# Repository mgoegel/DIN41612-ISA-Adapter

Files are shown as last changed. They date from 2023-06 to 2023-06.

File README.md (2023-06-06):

# DIN41612 to ISA Adapter

Here, I created a KiCad 6 Project.

The goal was, to create a PCB for debugging/testing of robotron EC1834 addon Boards on Standard XT PCs.

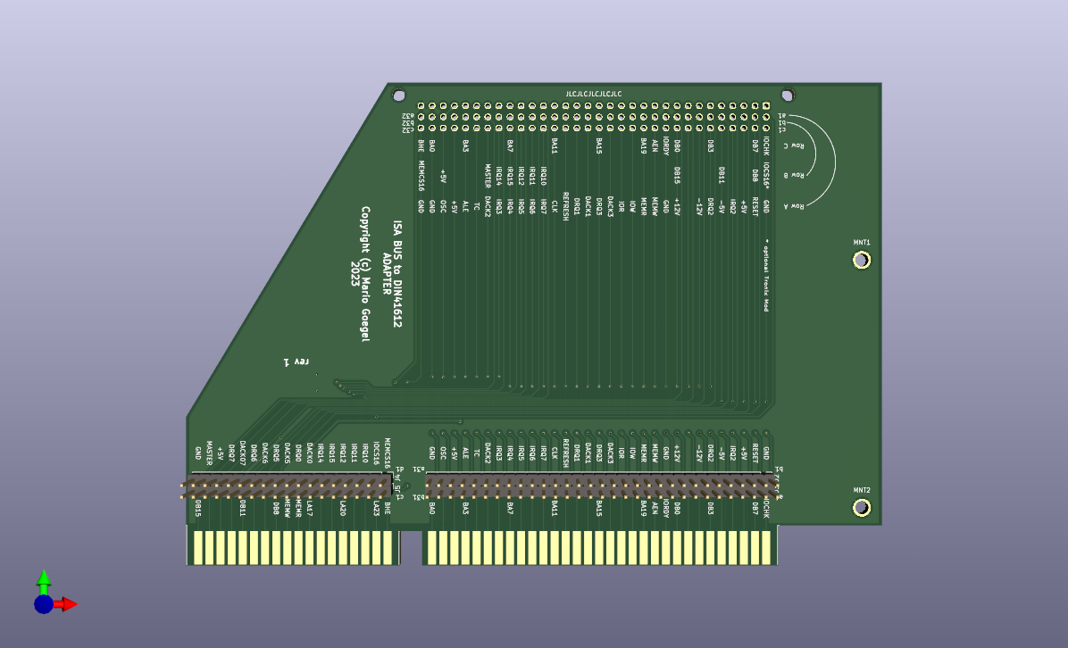
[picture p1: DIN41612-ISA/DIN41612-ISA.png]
DIN41612-ISA


[Schematics](DIN41612-ISA/DIN41612-ISA.pdf)

Below is the Bill of Materials for the board:

```
Ref(s)      Value                               Mouser P/N
-------------------------------------------------------------------------------
J1          DIN 41612 Type R a+b+c 3x32 PINs    649-8693968837V1LF  
            (96 PINs) Receptacles
J2, J3      13x1 header                         538-22-28-4200 (See Note 1)
J4, J5      31x1 header                         538-22-28-4200 (See Note 1)
BRACKET     Keystone 9202 ISA bracket           534-9202
SCREWS      4-40 x 1/4" machine screw           534-9301
```

But the 
Note 1: Order a 20 (or greater) breakaway header, break into the required lengths.

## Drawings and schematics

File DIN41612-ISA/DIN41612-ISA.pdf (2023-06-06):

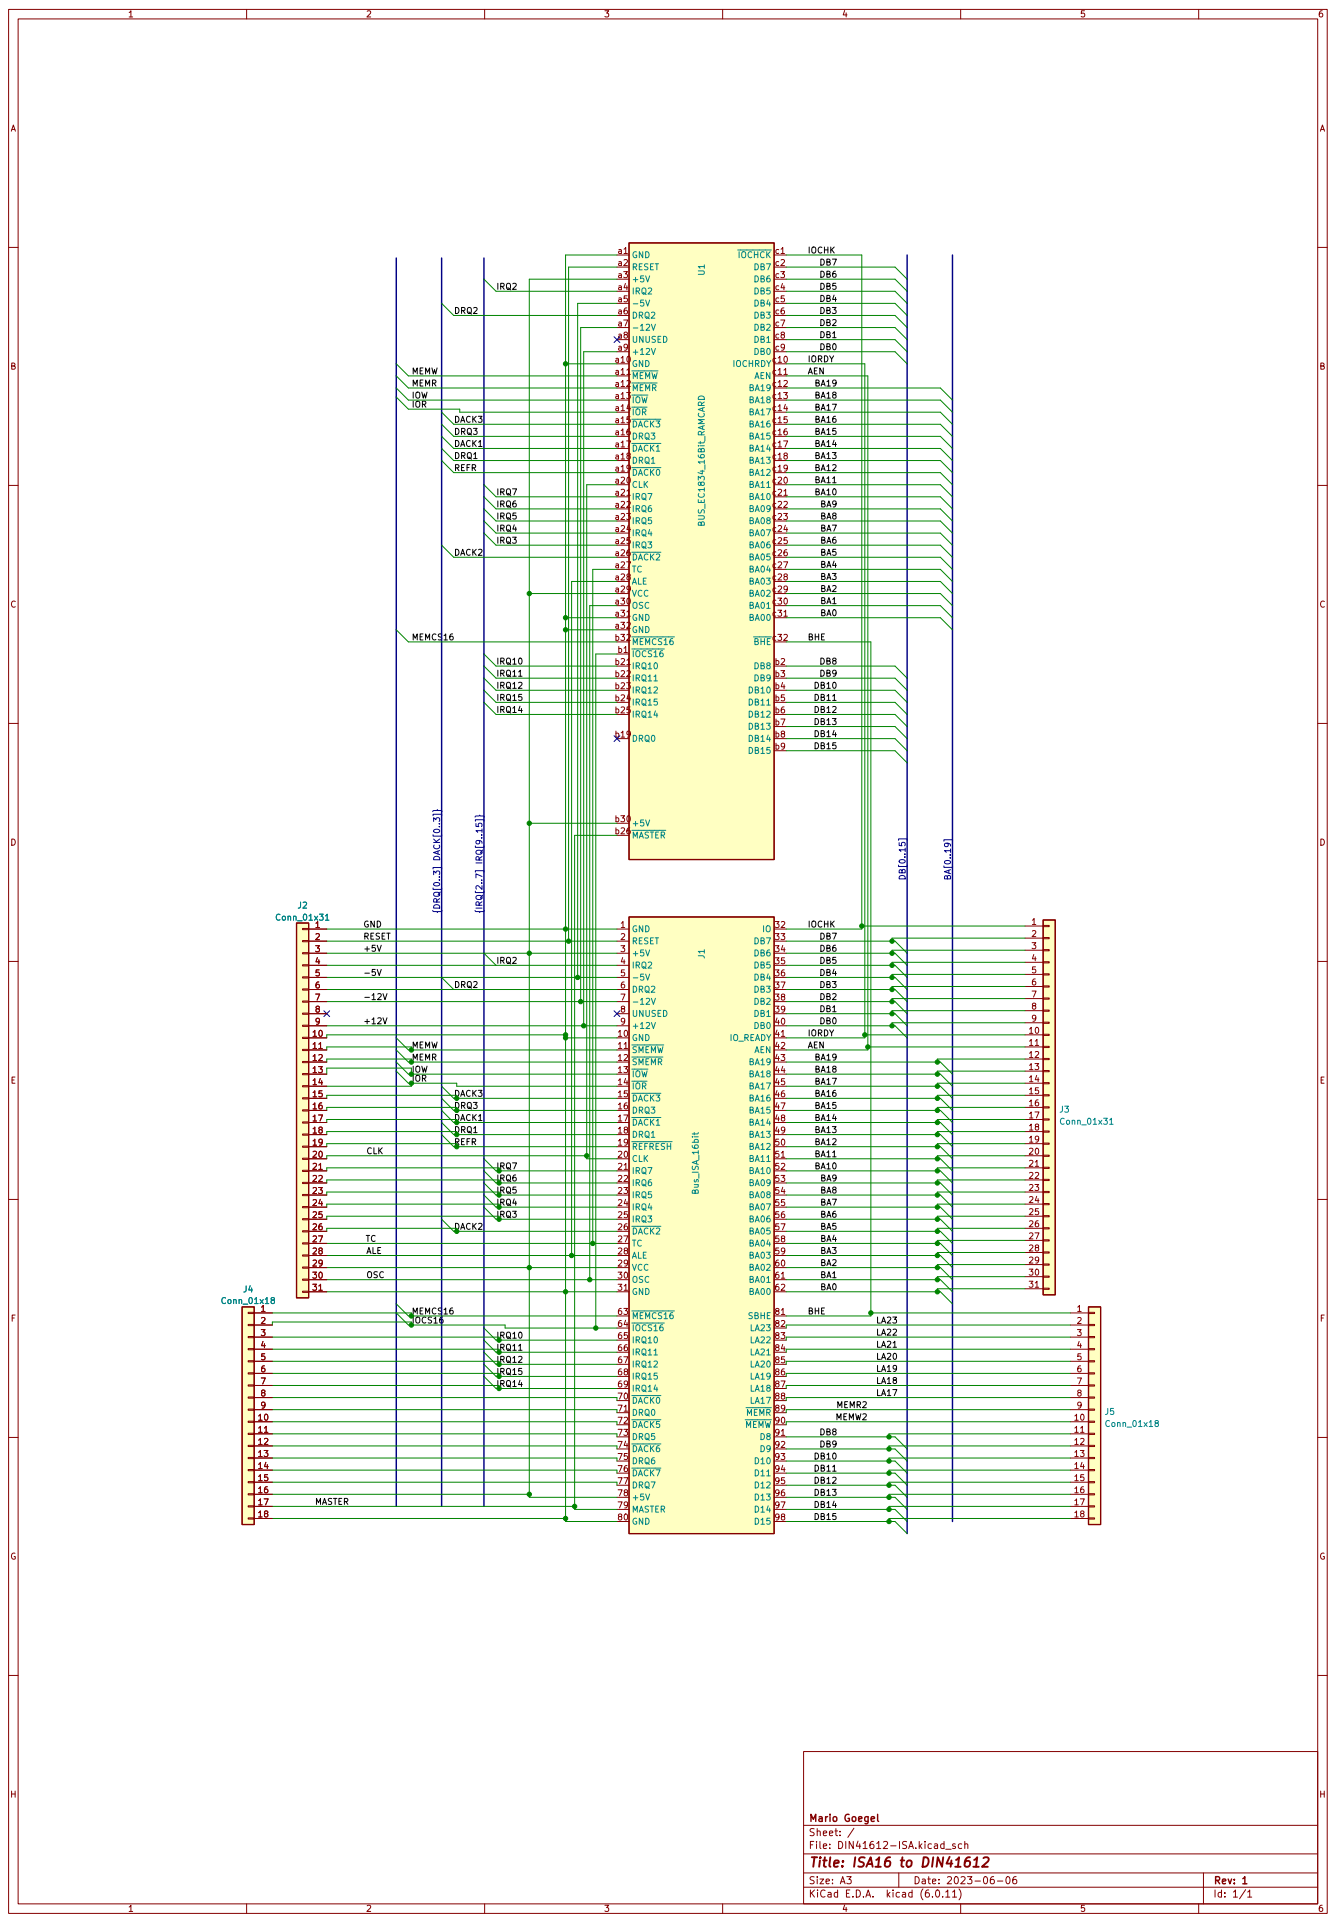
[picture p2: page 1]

-5V | | IRQ2 DRQ2 | IORDY DB0 DB2 DB7 DB3 DB6 DB4
+5V | MEMR

IRQ3 IRQ10 IRQ12 IRQ14 | 78 | DB11 TCOSC DB9 ALE MEMW2 BA3 MASTER IRQ10 65 IRQ11 66 IRQ12 67 IRQ15 68 IRQ14 69 MASTER 79

BA0 DB14 DB12 DB15 DB13 DB10 DB8 LA23 82 LA22 83 84 LA21 LA20 85 LA19 86 LA18 87 LA17 MEMR2 88 ~{MEMR} 89 | 1823456789 10 11

12
13
14
15
16

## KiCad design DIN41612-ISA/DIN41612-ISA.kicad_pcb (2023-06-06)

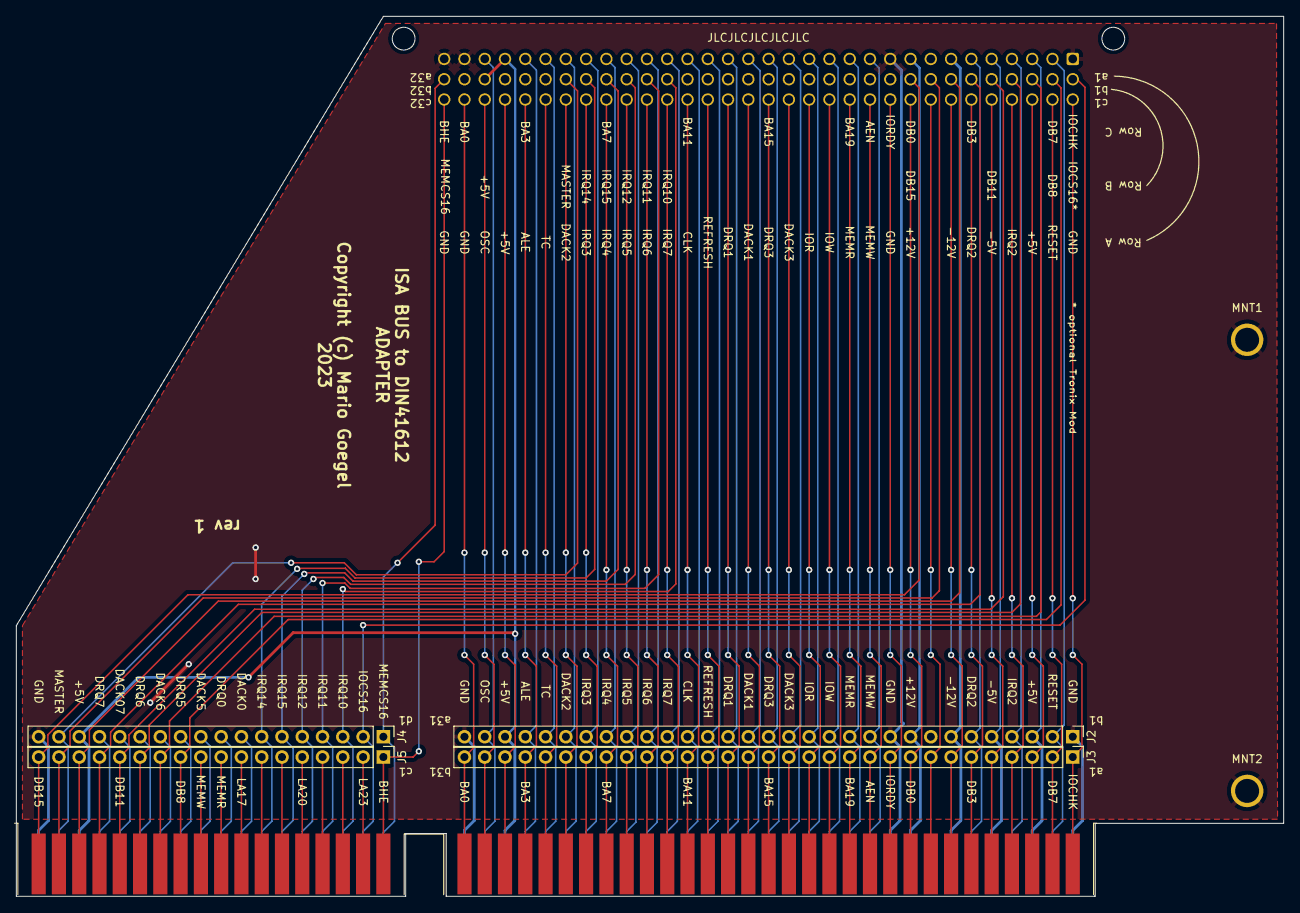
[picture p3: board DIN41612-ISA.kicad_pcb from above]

Board: 2 copper layers, 158.8 x 110.2 mm, 8 parts (1 on the bottom side), 92 nets.

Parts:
J1: Bus_ISA_16bit; BUS_AT
J2, J3: Conn_01x31; PinHeader_1x31_P2.54mm_Vertical
J4, J5: Conn_01x18; PinHeader_1x18_P2.54mm_Vertical
MNT1, MNT2: MountingHole_3mm_Pad
U1: BUS_EC1834_16Bit_RAMCARD; DIN41612_C_3x32_Male_Horizontal_THT_PressFit

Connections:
/+5V: J1.3 (+5V), J1.29 (VCC), J1.78 (+5V), J2.3, J2.29, J4.16, U1.a3 (+5V), U1.a29 (VCC), U1.b30 (+5V)
/+12V: J1.9 (+12V), J2.9, U1.a9 (+12V)
/-5V: J1.5 (-5V), J2.5, U1.a5 (-5V)
/-12V: J1.7 (-12V), J2.7, U1.a7 (-12V)
/AEN: J1.42 (AEN), J3.11, U1.c11 (AEN)
/ALE: J1.28 (ALE), J2.28, U1.a28 (ALE)
/BA0: J1.62 (BA00), J3.31, U1.c31 (BA00)
/BA1: J1.61 (BA01), J3.30, U1.c30 (BA01)
/BA2: J1.60 (BA02), J3.29, U1.c29 (BA02)
/BA3: J1.59 (BA03), J3.28, U1.c28 (BA03)
/BA4: J1.58 (BA04), J3.27, U1.c27 (BA04)
/BA5: J1.57 (BA05), J3.26, U1.c26 (BA05)
/BA6: J1.56 (BA06), J3.25, U1.c25 (BA06)
/BA7: J1.55 (BA07), J3.24, U1.c24 (BA07)
/BA8: J1.54 (BA08), J3.23, U1.c23 (BA08)
/BA9: J1.53 (BA09), J3.22, U1.c22 (BA09)
/BA10: J1.52 (BA10), J3.21, U1.c21 (BA10)
/BA11: J1.51 (BA11), J3.20, U1.c20 (BA11)
/BA12: J1.50 (BA12), J3.19, U1.c19 (BA12)
/BA13: J1.49 (BA13), J3.18, U1.c18 (BA13)
/BA14: J1.48 (BA14), J3.17, U1.c17 (BA14)
/BA15: J1.47 (BA15), J3.16, U1.c16 (BA15)
/BA16: J1.46 (BA16), J3.15, U1.c15 (BA16)
/BA17: J1.45 (BA17), J3.14, U1.c14 (BA17)
/BA18: J1.44 (BA18), J3.13, U1.c13 (BA18)
/BA19: J1.43 (BA19), J3.12, U1.c12 (BA19)
/BHE: J1.81 (SBHE), J5.1, U1.c32 (~BHE)
/CLK: J1.20 (CLK), J2.20, U1.a20 (CLK)
/DACK1: J1.17 (~DACK1), J2.17, U1.a17 (~DACK1)
/DACK2: J1.26 (~DACK2), J2.26, U1.a26 (~DACK2)
/DACK3: J1.15 (~DACK3), J2.15, U1.a15 (~DACK3)
/DB0: J1.40 (DB0), J3.9, U1.c9 (DB0)
/DB1: J1.39 (DB1), J3.8, U1.c8 (DB1)
/DB2: J1.38 (DB2), J3.7, U1.c7 (DB2)
/DB3: J1.37 (DB3), J3.6, U1.c6 (DB3)
/DB4: J1.36 (DB4), J3.5, U1.c5 (DB4)
/DB5: J1.35 (DB5), J3.4, U1.c4 (DB5)
/DB6: J1.34 (DB6), J3.3, U1.c3 (DB6)
/DB7: J1.33 (DB7), J3.2, U1.c2 (DB7)
/DB8: J1.91 (D8), J5.11, U1.b2 (DB8)
/DB9: J1.92 (D9), J5.12, U1.b3 (DB9)
/DB10: J1.93 (D10), J5.13, U1.b4 (DB10)
/DB11: J1.94 (D11), J5.14, U1.b5 (DB11)
/DB12: J1.95 (D12), J5.15, U1.b6 (DB12)
/DB13: J1.96 (D13), J5.16, U1.b7 (DB13)
/DB14: J1.97 (D14), J5.17, U1.b8 (DB14)
/DB15: J1.98 (D15), J5.18, U1.b9 (DB15)
/DRQ1: J1.18 (DRQ1), J2.18, U1.a18 (DRQ1)
/DRQ2: J1.6 (DRQ2), J2.6, U1.a6 (DRQ2)
/DRQ3: J1.16 (DRQ3), J2.16, U1.a16 (DRQ3)
/GND: J1.1 (GND), J1.10 (GND), J1.31 (GND), J1.80 (GND), J2.1, J2.10, J2.31, J4.18, MNT1.1, MNT2.1, U1.a1 (GND), U1.a10 (GND), U1.a31 (GND), U1.a32 (GND)
/IOCHK: J1.32 (IO), J3.1, U1.c1 (~IOCHCK)
/IOCS16: J1.64 (~IOCS16), J4.2, U1.b1 (~IOCS16)
/IOR: J1.14 (~IOR), J2.14, U1.a14 (~IOR)
/IORDY: J1.41 (IO_READY), J3.10, U1.c10 (IOCHRDY)
/IOW: J1.13 (~IOW), J2.13, U1.a13 (~IOW)
/IRQ2: J1.4 (IRQ2), J2.4, U1.a4 (IRQ2)
/IRQ3: J1.25 (IRQ3), J2.25, U1.a25 (IRQ3)
/IRQ4: J1.24 (IRQ4), J2.24, U1.a24 (IRQ4)
/IRQ5: J1.23 (IRQ5), J2.23, U1.a23 (IRQ5)
/IRQ6: J1.22 (IRQ6), J2.22, U1.a22 (IRQ6)
/IRQ7: J1.21 (IRQ7), J2.21, U1.a21 (IRQ7)
/IRQ10: J1.65 (IRQ10), J4.3, U1.b21 (IRQ10)
/IRQ11: J1.66 (IRQ11), J4.4, U1.b22 (IRQ11)
/IRQ12: J1.67 (IRQ12), J4.5, U1.b23 (IRQ12)
/IRQ14: J1.69 (IRQ14), J4.7, U1.b25 (IRQ14)
/IRQ15: J1.68 (IRQ15), J4.6, U1.b24 (IRQ15)
/LA17: J1.88 (LA17), J5.8
/LA18: J1.87 (LA18), J5.7
/LA19: J1.86 (LA19), J5.6
/LA20: J1.85 (LA20), J5.5
/LA21: J1.84 (LA21), J5.4
/LA22: J1.83 (LA22), J5.3
/LA23: J1.82 (LA23), J5.2
/MASTER: J1.79 (MASTER), J4.17, U1.b26 (~MASTER)
/MEMCS16: J1.63 (~MEMCS16), J4.1, U1.b32 (~MEMCS16)
/MEMR: J1.12 (~SMEMR), J2.12, U1.a12 (~MEMR)
/MEMR2: J1.89 (~MEMR), J5.9
/MEMW: J1.11 (~SMEMW), J2.11, U1.a11 (~MEMW)
/MEMW2: J1.90 (~MEMW), J5.10
/OSC: J1.30 (OSC), J2.30, U1.a30 (OSC)
/REFR: J1.19 (~REFRESH), J2.19, U1.a19 (~DACK0)
/RESET: J1.2 (RESET), J2.2, U1.a2 (RESET)
/TC: J1.27 (TC), J2.27, U1.a27 (TC)
unnamed: J1.70 (~DACK0), J4.8
unnamed: J1.71 (DRQ0), J4.9
unnamed: J1.72 (~DACK5), J4.10
unnamed: J1.73 (DRQ5), J4.11
unnamed: J1.74 (~DACK6), J4.12
unnamed: J1.75 (DRQ6), J4.13
unnamed: J1.76 (~DACK7), J4.14
unnamed: J1.77 (DRQ7), J4.15

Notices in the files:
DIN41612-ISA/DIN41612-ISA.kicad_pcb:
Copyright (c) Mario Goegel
